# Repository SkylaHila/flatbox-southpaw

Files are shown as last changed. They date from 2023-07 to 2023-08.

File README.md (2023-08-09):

# Flatbox-southpaw: Rev5 Flatbox with mirrored case and rerouted PCB for left handed players!

Controller is finished and 100% confirmed working! 

This repository contains 3D-printable models, PCB design files and code needed to make an arcade controller that looks like this:

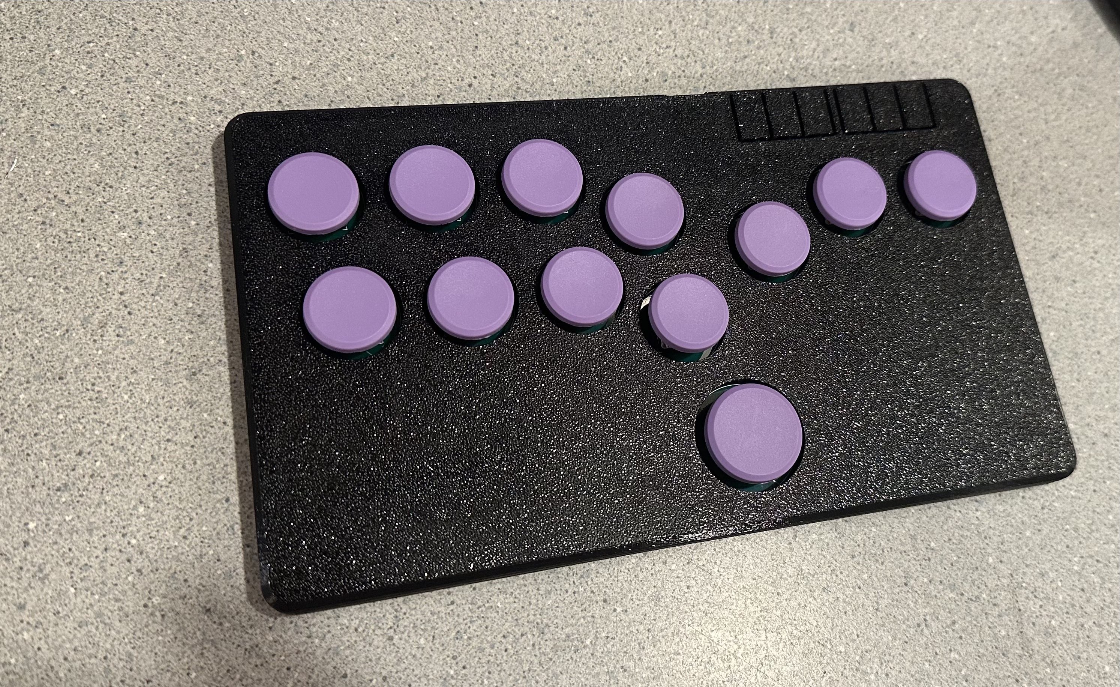
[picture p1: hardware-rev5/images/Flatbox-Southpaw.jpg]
Assembled Flatbox


The only version that has had the mirroring performed is the [rev5](hardware-rev5)

[rev5](hardware-rev5)
---------------------
case dimensions | 218x126x10mm

compatibility (using provided firmware) | PC, PS3

add-on board | [RP2040-Zero](https://www.waveshare.com/rp2040-zero.htm)

onboard chip | RP2040 

port | USB-C

SMT assembly required | no

firmware | [RP2040](firmware-rp2040)

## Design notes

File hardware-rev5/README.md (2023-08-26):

# Flatbox rev5

This is rev5 of the Flatbox. In this version an [RP2040-Zero](https://www.waveshare.com/rp2040-zero.htm) board is soldered onto the main PCB.

To make one you will need:

* [3D printed case parts](3d-printed-case) - top and bottom
* [the Flatbox PCB](pcb)
* [RP2040-Zero](https://www.waveshare.com/rp2040-zero.htm)
* 12x Kailh low profile (choc v1) switches of your choice
* (optionally) 12x Kailh low profile hotswap sockets
* [3D printed buttoncaps](../3d-printed-buttoncaps)
* 6x 6x6x5mm tact switches
* 7x M3x6 flat head screws
* some kind of rubber feet or non-slip padding for the bottom
* a soldering iron

I printed the case at 0.20mm layer height. The top part should be printed upside-down, the bottom part should be printed as-is. They don't require supports.

The PCB can be ordered from a number of online services using the included [Gerber files](pcb), I used [JLCPCB](https://jlcpcb.com/) (leave all the settings at default, you can choose the PCB color). PCB thickness should be 1.6mm.

The switches can be soldered in directly to the PCB or you can use hotswap sockets. If you want to use hotswap sockets, you will have to print the appropriate bottom part of the case (it's 1mm thicker).

The firmware in the folder can be installed and is preconfigured for this controller. It is a preconfigured version of the GP2040-CE firmware available at https://gp2040-ce.info

To flash the firmware, connect the board to a computer with a USB cable, then press the RESET button while holding the BOOT button on the RP2040-Zero. A drive named "RPI-RP2" should appear. Copy the firmware to the drive, wait for it to finish uploading, and then after a few seconds, unplug the RP2040-Zero. 

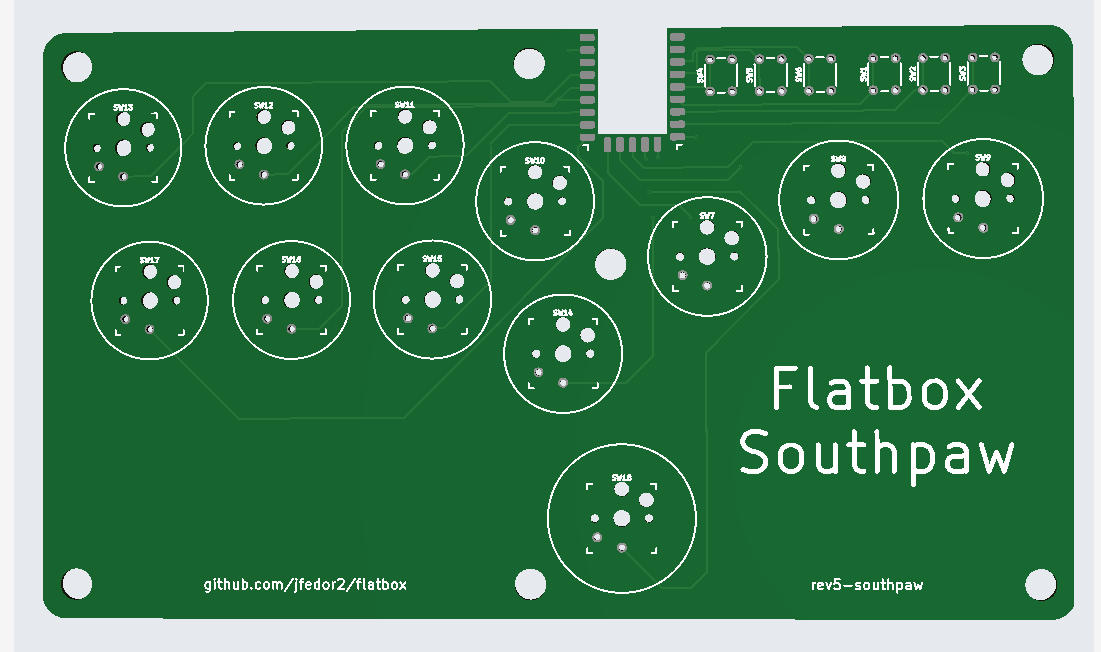
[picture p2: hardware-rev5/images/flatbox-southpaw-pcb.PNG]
Flatbox rev5 unpopulated PCB


RP2040-Zero soldered on top of the PCB

Flatbox rev5 exploded view of the 3D printed case

PCB design licensed under [CC BY-SA 4.0](https://creativecommons.org/licenses/by-sa/4.0/).

PCB design uses the following:

* [keyswitches.pretty](https://github.com/daprice/keyswitches.pretty) by [daprice](https://github.com/daprice) ([CC BY-SA 4.0](https://creativecommons.org/licenses/by-sa/4.0/))
* RP2040-Zero STEP file downloaded from [Waveshare wiki](https://www.waveshare.com/wiki/RP2040-Zero)

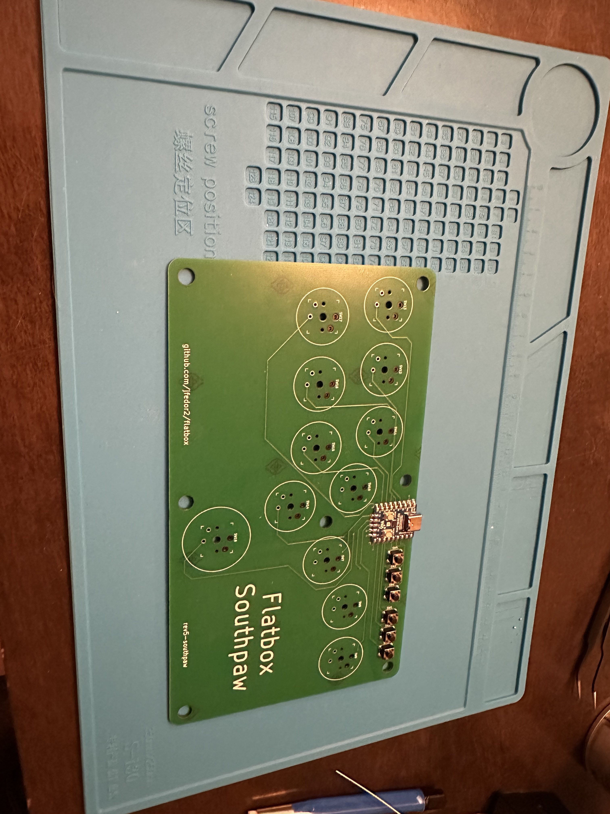
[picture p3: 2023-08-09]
hardware-rev5/images/flatbox-southpaw-pcb1.jpg

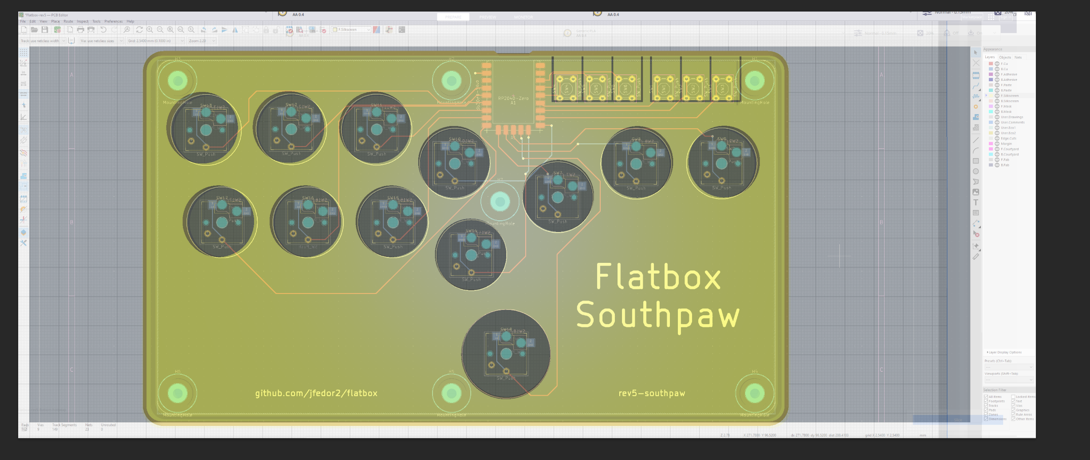
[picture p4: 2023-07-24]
hardware-rev5/images/flatbox.PNG

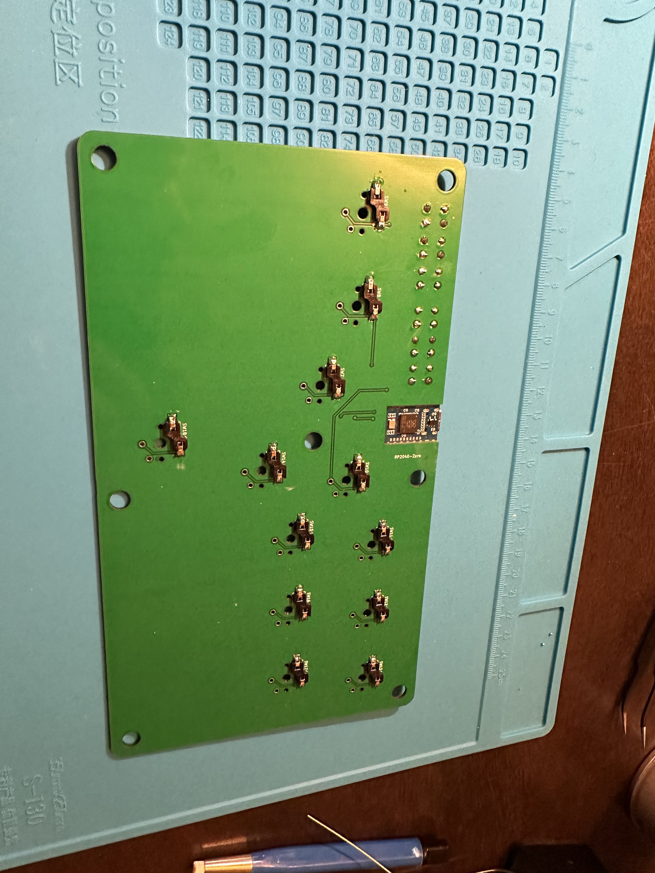
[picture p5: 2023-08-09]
hardware-rev5/images/flatbox-southpaw-pcb.jpg

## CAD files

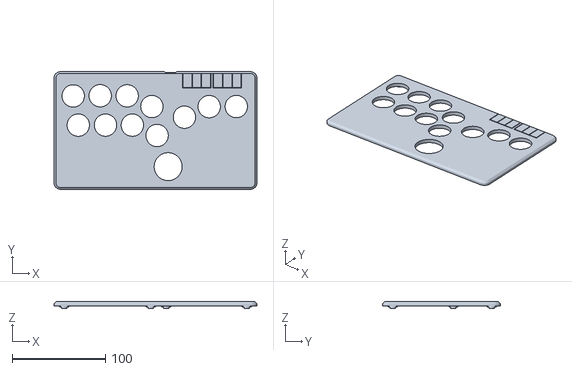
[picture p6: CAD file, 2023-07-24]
hardware-rev5/3d-printed-case/Flatbox-rev5-southpaw-Top.stl
218.0 x 126.4 x 7.20

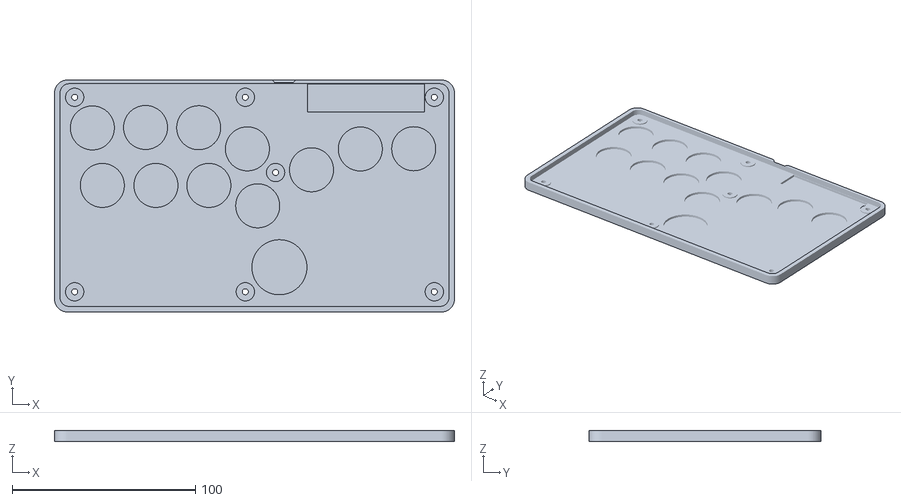
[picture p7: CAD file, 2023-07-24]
hardware-rev5/3d-printed-case/Flatbox-rev5-southpaw-Bottom-hotswap.stl
218.0 x 126.4 x 6.20

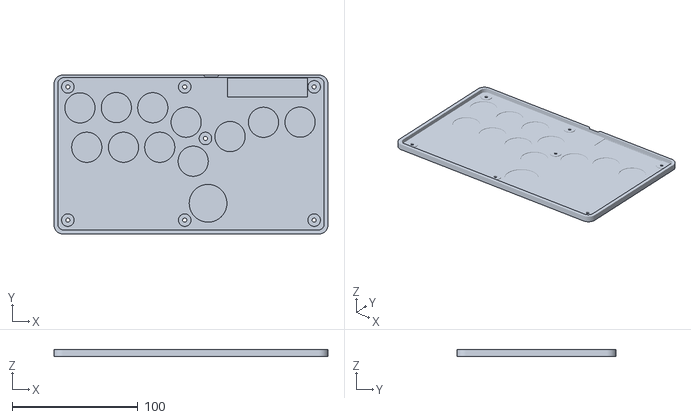
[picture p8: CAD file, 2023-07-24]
hardware-rev5/3d-printed-case/Flatbox-rev5-southpaw-Bottom.stl
218.0 x 126.4 x 5.20

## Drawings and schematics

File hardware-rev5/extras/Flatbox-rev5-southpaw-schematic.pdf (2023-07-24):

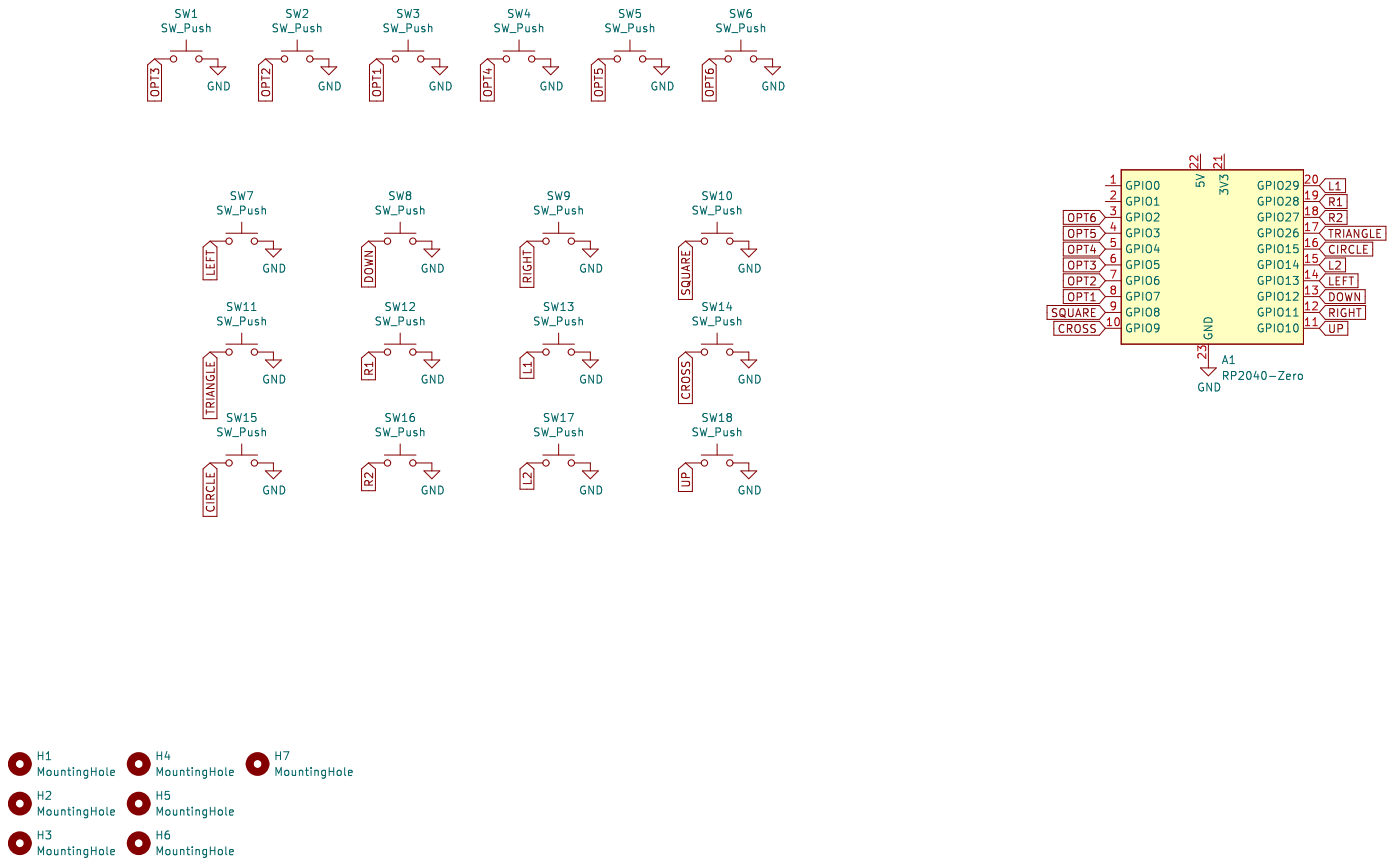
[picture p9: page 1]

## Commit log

2023-07-24 Flatbox-southpaw WIP image
    Image of mirrored case with mirrored and rerouted PCB to use on the main page until the controller is actually finished
2023-07-24 Add files via upload
    All the .stl files that are needed for the south-paw
    [Flatbox-rev5-southpaw-Bottom-hotswap.stl, Flatbox-rev5-southpaw-Bottom.stl, Flatbox-rev5-southpaw-Top.stl]
2023-07-24 Add files via upload
    Added southpaw PCB gerber files
2023-07-24 Uploaded southpaw flatbox rev5 kicad files
2023-07-24 Southpaw PCB 3d model
2023-07-24 Update README.md
    Updated Rev5 readme to include image of southpaw PCB
2023-07-24 3D model of southpaw PCB
2023-07-24 Delete flatbox-southpaw pcb.PNG
    added file with correct filename
2023-07-24 Delete hardware-rev1.1 directory
    Irrelevant to southpaw fork
    [Flatbox-rev1.1-Bottom-hotswap.stl, Flatbox-rev1.1-Bottom.stl, Flatbox-rev1.1-Top.stl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]
2023-07-24 Delete hardware-rev1 directory
    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
    [Flatbox-rev1b-Bottom-hotswap.stl, Flatbox-rev1b-Bottom.stl, Flatbox-rev1b-Top.stl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]
2023-07-24 Delete hardware-rev2 directory
    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
    [Flatbox-rev2-BOM.csv, Flatbox-rev2b-Bottom-hotswap.stl, Flatbox-rev2b-Bottom.stl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]
2023-07-24 Delete hardware-rev3 directory
    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
    [Flatbox-rev3-BOM.csv, Flatbox-rev3-Bottom-hotswap.stl, Flatbox-rev3-Bottom.stl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]
2023-07-24 Delete hardware-rev4 directory
    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
    [Flatbox-rev4-BOM.csv, Flatbox-rev4-Bottom-hotswap.stl, Flatbox-rev4-Bottom.stl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]
2023-07-24 Delete Flatbox-rev5-gerber.zip
    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
2023-07-24 Delete Flatbox-rev5-kicad.zip
    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
2023-07-24 Delete Flatbox-rev5-schematic.pdf
    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
2023-07-24 Add files via upload
    Updated schematic for southpaw PCB
2023-07-24 Add files via upload
    Updated PCB to link to this repo
2023-07-24 Add files via upload
    Updated PCB to reference this repo
2023-07-24 Modify pin definitions
